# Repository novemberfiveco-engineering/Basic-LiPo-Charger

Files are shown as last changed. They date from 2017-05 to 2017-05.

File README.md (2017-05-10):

# Basic LiPo Charger

[This breakout](https://www.tindie.com/products/novemberfive/basic-lipo-battery-charger/) uses the [MCP73831](http://www.microchip.com/wwwproducts/en/en024903). It's ideal for charging LiPo batteries in space-limited, cost-sensitive applications and designed with adjustable charging rate (15mA - 500mA).

## Features

* Programmable Charge Current: 15mA to 500mA
* Provided with status LED
* Battery connection JST-type
* Micro-USB power connector
* Input voltage 3.75 - 6V
* Provided place to fork current
* Demensions: 31.0 x 12.8 mm

For more information about the MCP73831 please click [here](http://www.microchip.com/wwwproducts/en/en024903)

## Where to get?
You can buy this item on Tindie from the [November Five's hardware shop](https://www.tindie.com/products/novemberfive/basic-lipo-battery-charger/).

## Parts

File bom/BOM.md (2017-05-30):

# Bill of Materials
### LiPo Battery Charger

Component Refs | Type            | Value      | Package                     | Qty | Farnell Part #
-------------- | --------------- | ---------- | ----------                  | :-: | -------------
D1             |   LED           |            |                    LED-0603 |    1| 2687488
R1             |   Resistor      |    150     |                       R0603 |    1| 2447255
R2             |   Resistor      |    2 K     |                       R0603 |    1| 2447319
C1, C2         |   Capacitor     |   4.7 µF   |                       C0603 |    2| 2627456
J1             |   Connector     |            | USB-MICRO-MOLEX-105017-0001 |    1| 2293836
J2             |   Connector     |            |                   JST-2-SMD |    1| 9492615
U1             |   IC            |            |                     SOT23-5 |    1| 1332158

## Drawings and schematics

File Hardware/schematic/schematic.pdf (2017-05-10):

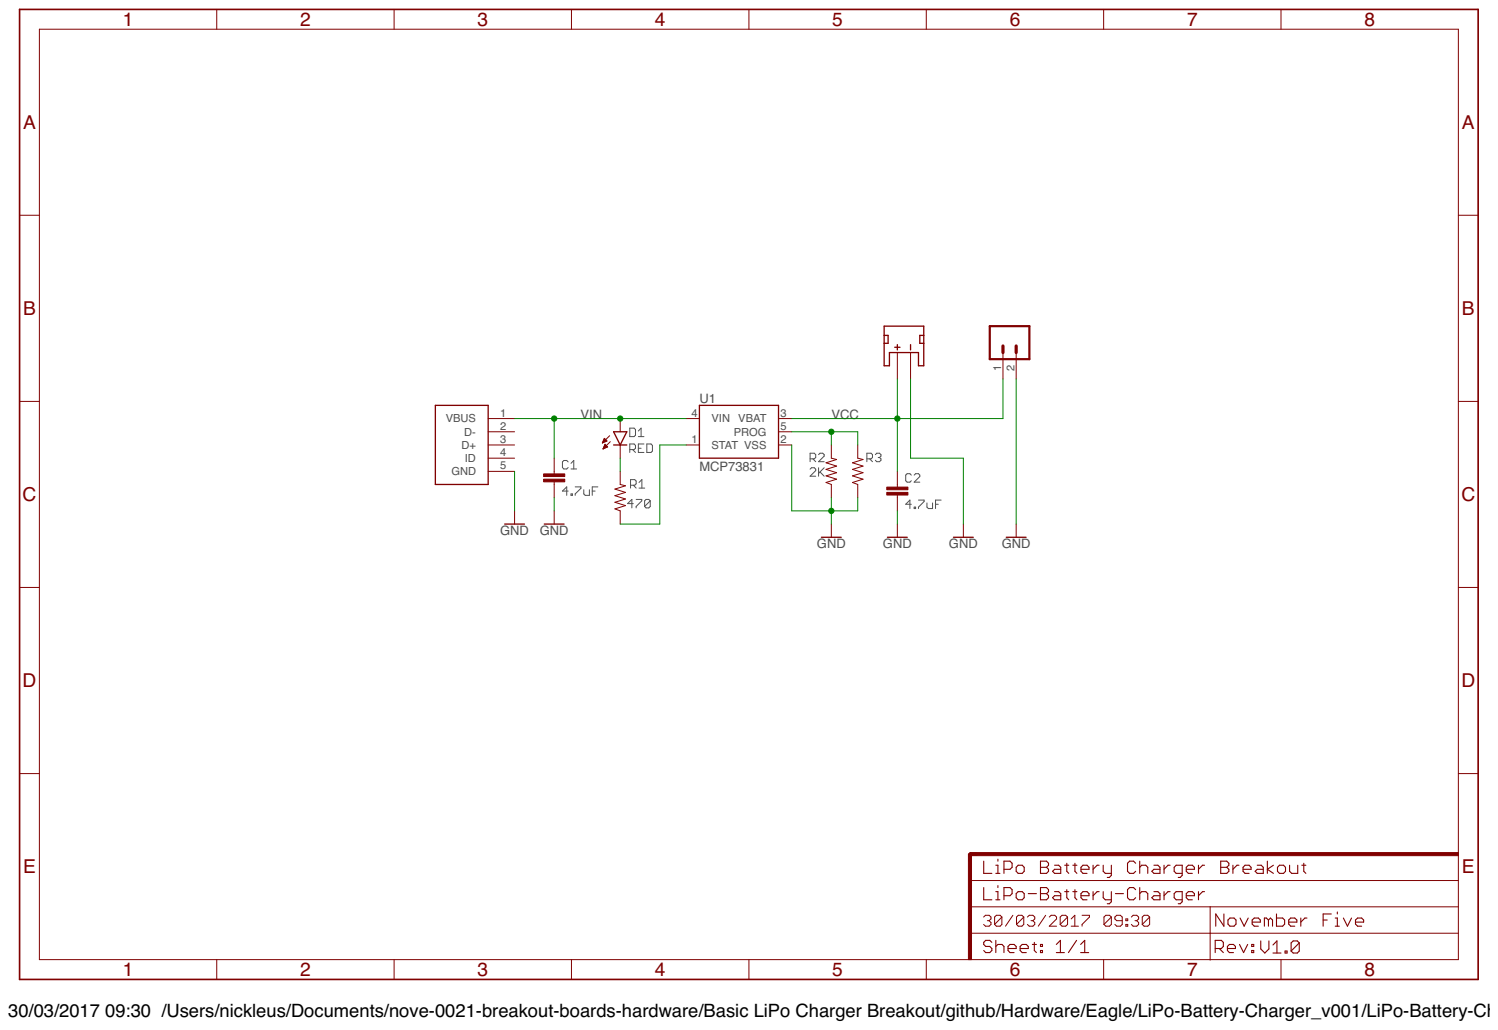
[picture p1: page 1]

30/03/2017 09:30 /Users/nickleus/Documents/nove-0021-breakout-boards-hardware/Basic LiPo Charger Breakout/github/Hardware/Eagle/LiPo-Battery-Charger_v001/LiPo-Battery-Charger.sch (Sheet: 1/1)

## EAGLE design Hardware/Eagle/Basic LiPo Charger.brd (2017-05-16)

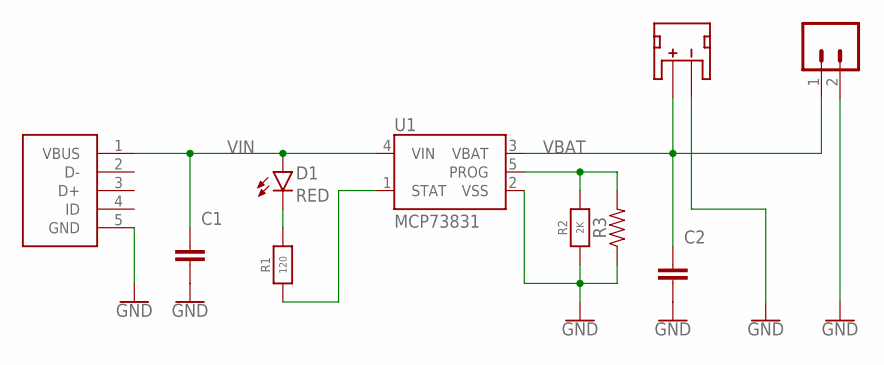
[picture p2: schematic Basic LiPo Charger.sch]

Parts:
C1, C2: 4.7uF; C0603
D1: RED; LED-0603
J1: USB-CON-5PIN-105017-0001; USB-MICRO-MOLEX-105017-0001
J2: JST_2MM_MALE; JST-2-SMD
J3: CONN_02; 1X02
R1: 120; R0603
R2: 2K; R0603
R3: 10MOHM-HORIZ-1/4W-5%; AXIAL-0.3
U1: MCP73831; SOT23-5

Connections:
GND: C1.2, C2.2, J1.5 (GND), J2.1 (-), J3.2, R2.1, R3.P$1 (1), U1.2 (VSS)
unnamed: D1.C, R1.2
PROG: R2.2, R3.P$2 (2), U1.5 (PROG)
STAT: R1.1, U1.1 (STAT)
VBAT: C2.1, J2.2 (+), J3.1, U1.3 (VBAT)
VIN: C1.1, D1.A, J1.1 (VBUS), U1.4 (VIN)

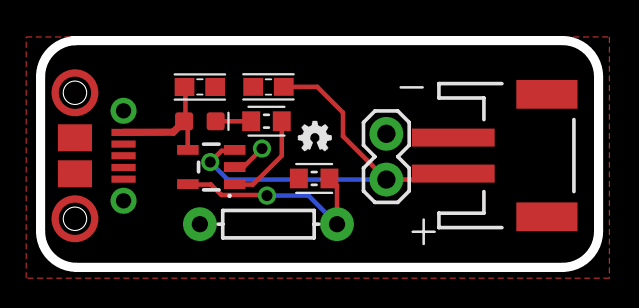
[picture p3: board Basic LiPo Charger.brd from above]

Board: 2 copper layers, 31.0 x 12.6 mm, 12 parts (0 on the bottom side), 6 nets.

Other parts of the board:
U$1: LOGO-NOVEMERFIVE-5SCALE
U$2: LOGO-OSHWA

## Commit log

2017-05-16 Changed resistor value
    [Basic LiPo Charger.brd, Basic LiPo Charger.sch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]
2017-05-16 Move via
    [Basic LiPo Charger.brd, Basic LiPo Charger.sch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]
2017-05-16 Add BOM

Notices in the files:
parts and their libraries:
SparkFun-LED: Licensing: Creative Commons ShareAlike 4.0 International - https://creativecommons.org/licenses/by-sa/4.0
